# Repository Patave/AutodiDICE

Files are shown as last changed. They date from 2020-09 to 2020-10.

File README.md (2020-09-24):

# AutodiDICE
Electronic DICE
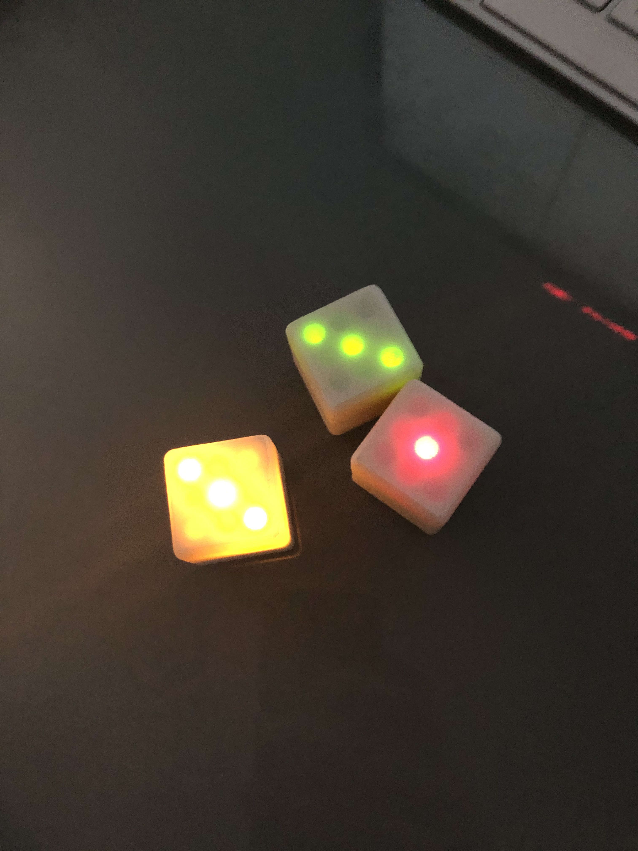
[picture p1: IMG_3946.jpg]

## Objectifs :

`Création Dé electronique sur base Attiny 85 et Attiny13A de A à Z`

Detection de vibration (switch mercure)

Mode Sleep et arret automatique après 7 secondes

Fonctionnel dans tous les sens (s'active sur un front montant du switch)

Ma Video: https://www.youtube.com/watch?v=F5hV5DrT228

3D STL Files: https://www.thingiverse.com/thing:4596834

Fichier GERBER pour production carte à souder

*Développement Electronique sous EasyEDA*

*Commande de cartes JLC-PCB*

### Principales réalisations : 

```
- Developpement Soft
  - Micro controlleur Attiny 85 + Evolution en Attiny13 pour encore diminuer le prix.
  - Fonction Sleep intégrée pour limiter la consommation
  - Animation du tirage dé amusante (rotation des leds) - pas possible pour la version Attiny13 (trop gros en octets)
  - V1.0: Verion Attiny85, v2.0: Version Attiny13

- Développement Electronique
  - réalisation sous EasyEDA
  - Génération image 3D (dans les fichiers joints)
  - Génération des fichiers GERBER pour lancement commande en Chine (JLC-PCB)

- Développpement boitier 3D
  - création du boitier sous Fusion 360
```

## Installation :

Attention à prévoir une petite découpe du support de pile pour laisser passer le microcontroleur

## Main components :

Attiny85: https://www.amazon.fr/Pièces-Attiny85-20PU-compatible-Arduino-A149/dp/B00OXVFD1I?pd_rd_w=Va80i&pf_rd_p=324a6047-fbee-4c30-8ff6-614657224ce8&pf_rd_r=Q6TFP13AJEMFBE4DBG9W&pd_rd_r=983145fe-9685-40ba-883b-0072b5635c12&pd_rd_wg=FvDhN&pd_rd_i=B00OXVFD1I&ref_=pd_bap_d_rp_1_11_t

Attiny13A (Evolution): https://fr.aliexpress.com/item/32751983292.html?spm=a2g0s.9042311.0.0.57206c37cBFwDP

Switch: https://fr.aliexpress.com/item/32605726248.html?spm=2114.13010708.0.0.3a996c37iu4wXC

Battery support: https://www.amazon.fr/GTIWUNG-Support-Adaptateurs-Batterie-Portables/dp/B0823WK4CN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

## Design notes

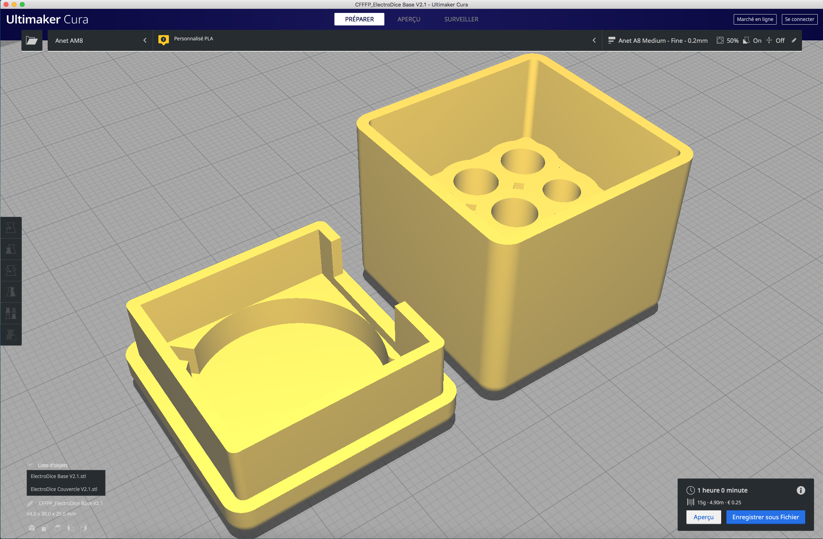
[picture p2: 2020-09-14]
Capture d’écran 2020-09-09 à 11.40.55.png

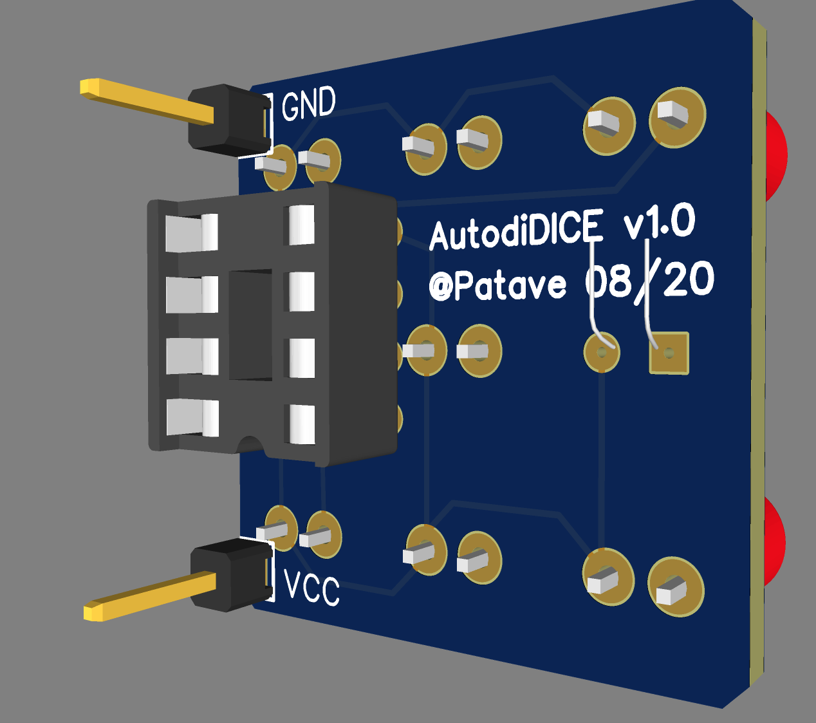
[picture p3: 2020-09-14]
Capture d’écran 2020-08-21 à 10.49.55.png

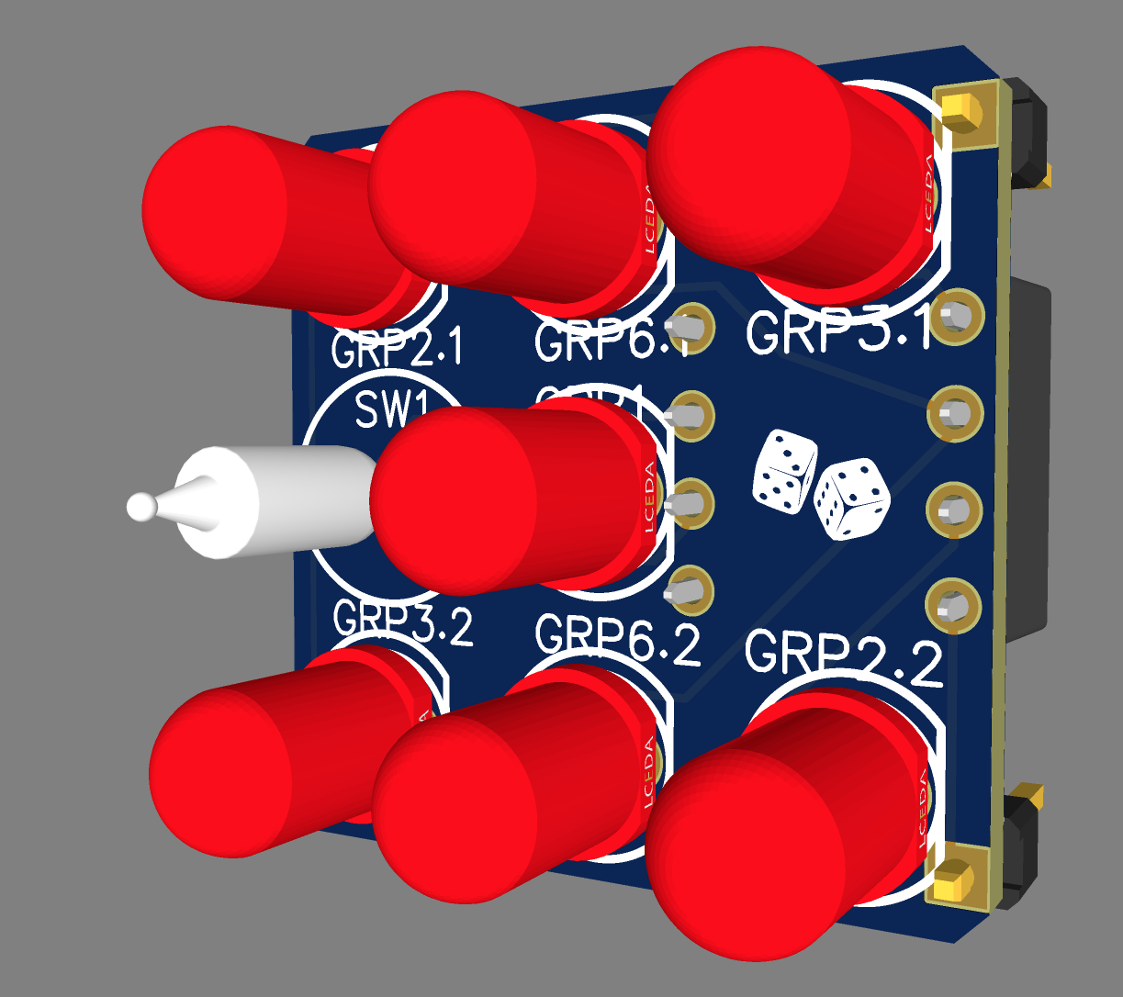
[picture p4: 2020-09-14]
Capture d’écran 2020-08-21 à 10.49.42.png

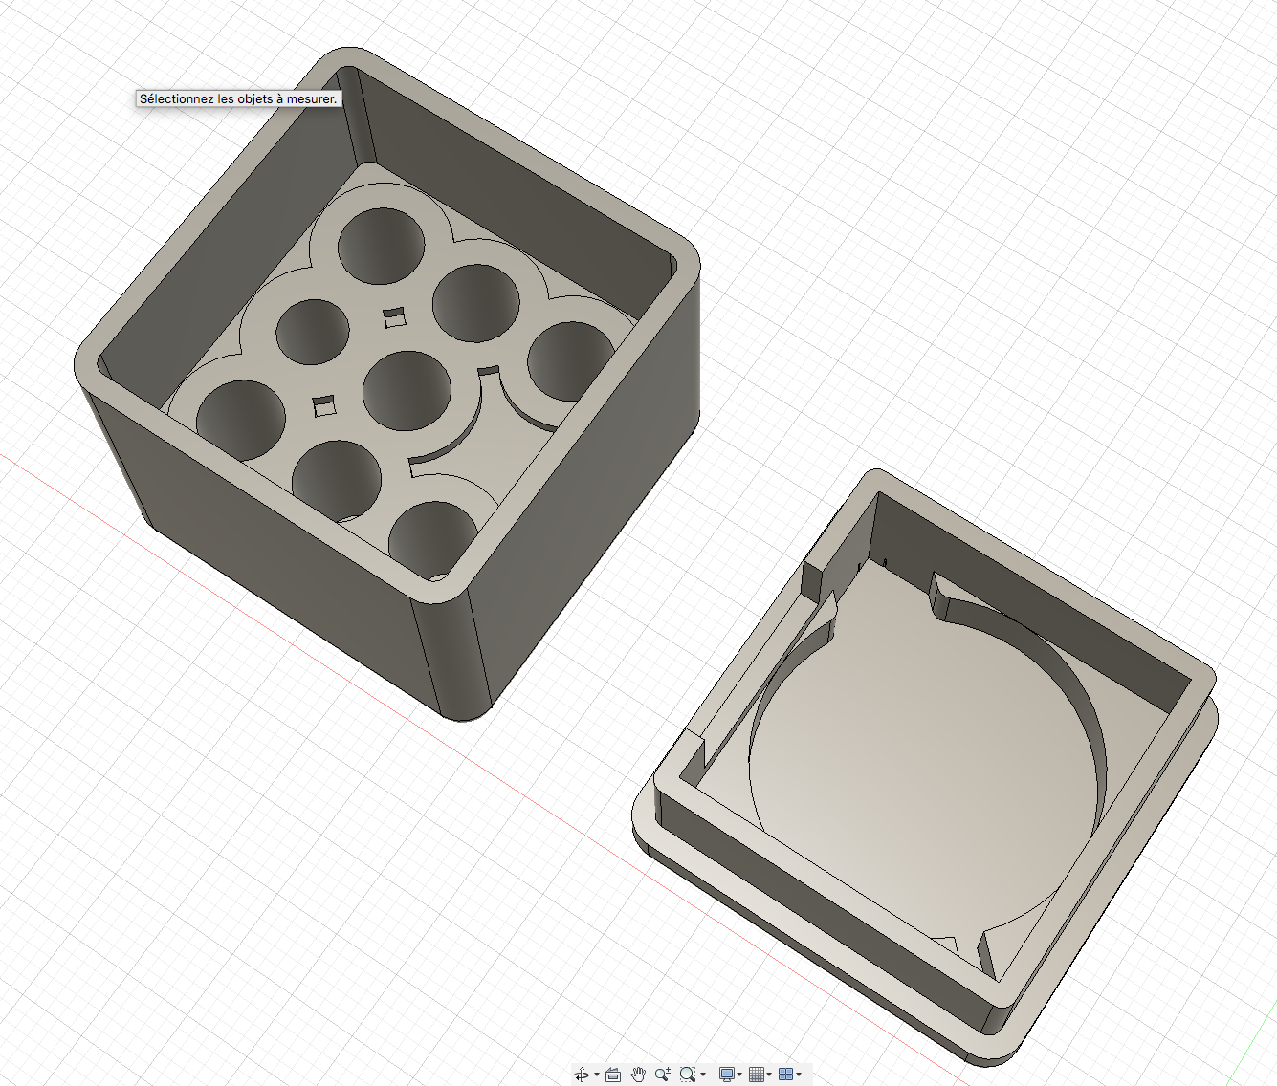
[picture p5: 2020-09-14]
Capture d’écran 2020-09-09 à 11.27.33.png

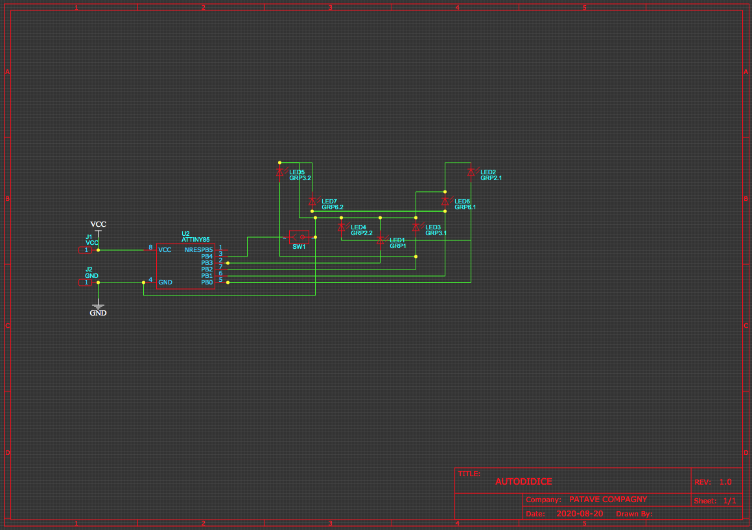
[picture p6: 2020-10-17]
AutodiDice Schema V1.0 2020-10-17.png

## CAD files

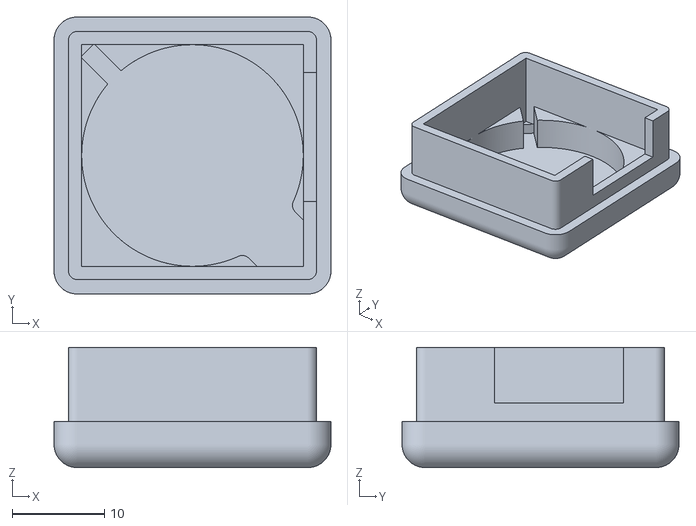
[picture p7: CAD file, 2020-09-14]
ElectroDice Base V2.1.stl
30.0 x 30.0 x 13.0

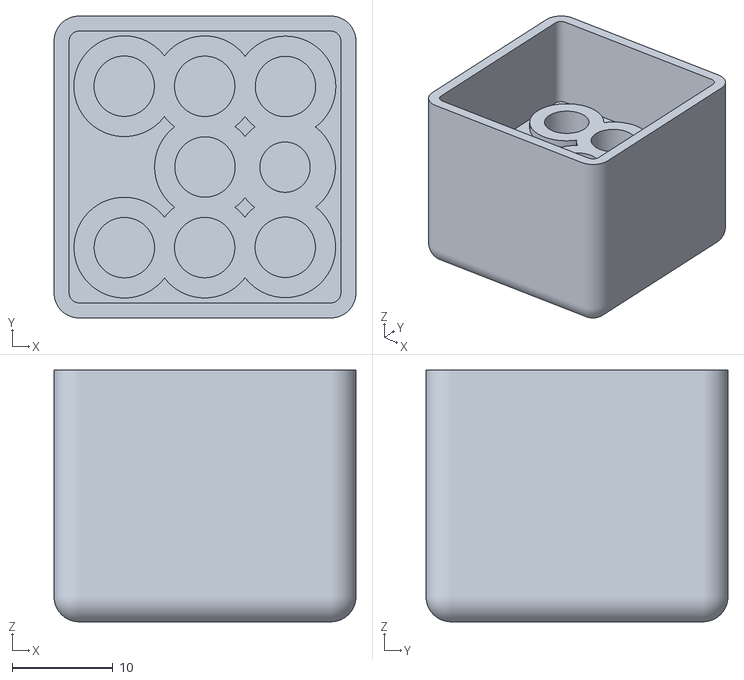
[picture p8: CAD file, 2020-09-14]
ElectroDice Couvercle V2.1.stl
30.0 x 30.0 x 25.0

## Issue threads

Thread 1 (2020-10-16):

schematics

claude1000, 2020-10-16:
Dear
could you post the schematics of the dice ?

nice job
thanks
Claude

Patave, 2020-10-17:
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

Hi Claude,
I will do.
But you have the gerber files if you want.
Patrick

Patave, 2020-10-17:
Claude, The schematic is now available

claude1000, 2020-10-20:
thanks a lot

Closed 2020-10-17.

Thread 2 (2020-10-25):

Led current-limiting resistor

claude1000, 2020-10-25:
Dear
Is there no need of resistors connected in serie with the led's  (  current-limiting resistor) ?
thanks a lot for the help
Claude

Patave, 2020-10-25:
No, with a battery 2032 it's ok

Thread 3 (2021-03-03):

Random not working?

rods, 2021-03-03:
I tried using ATTiny85 and ATTiny14 but the result is always 2, 4 or 6. There are no odd ones.
Compiled the v2 for both and v1 for ATTiny85. Results are the same

Patave, 2021-03-04:
Hi @rods , no reasons to randomize only for even numbers. Or you are very lucky.
I think that you have an hardware issue with the middle led.

rods, 2021-03-04:
Sorry @Patave ! shame on me!!! The center LED was down...fixed! This project is awesome...

Patave, 2021-03-04:
Great

Closed 2021-03-04.

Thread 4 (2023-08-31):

Attiny13

superjasiek, 2023-08-31:
Hi first have to say that it's realy  nice project. i made some dice with two types of chip - attiny85 and attiny13 i noticed that code with attiny13 consume much more power.
Dice with attiny85 last for weeks but dice with attiny13 works for maximum 6 days. Can you give me any hint how to solve the problem?
Thank you in advance for help.
Take care!

Patave, 2023-09-01:
@superjasiek You're right, I had the same behaviour.
The low consuption doesnt works. I have not investigate currently.

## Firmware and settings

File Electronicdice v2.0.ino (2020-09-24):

//------------------------------
// Dé électronique sur ATtiny13
// (C) 2020, Patrick Aversenq
//------------------------------
// Version "2.0", 24 september 2020

#include <avr/io.h>
#include <avr/sleep.h>
#include <avr/interrupt.h>
#include <util/delay.h>

// ----- DECLARATION DES VARIABLES ------

// Ports utilisée pour les groupes de LED:
//#define PortLeds PORTB
//#define BitUn PB3   // UN  (1 led centrale)
//#define BitDeux PB2 // DEUX (2 leds en coin)
//#define BitTrois PB0 // TROIS (2 leds en coin opposés)
//#define BitSix PB1 // SIX (2 leds milieu)

//#define PortButton PINB
//#define buttonPin PB4  //Capteur d'inclinaison


// Déclarations

int buttonState; //Etat du capteur d'inclinaison
int buttonPreviousState; //Etat capteur inclinaison précédent

unsigned long previousMillis = 0; //Time for activity

// Nombre de msseconde avant le sleep (Time Before Sleep)
#define Sleepdelay 7000


// Procédure pour afficher la valeur;
void Display (volatile byte *port, long valeur) {
   //Reset Port
   *port &= ~(_BV(PB0)|_BV(PB1)|_BV(PB2)|_BV(PB3));
   
   //Bit 1 (if value not even)
   if (valeur%2 != 0) *port |= _BV(PB3);
   
   //Bit 2 (if value > 1)
   if (valeur > 1) *port |= _BV(PB2);
  
   //Bit 3 (if value > 3)
   if (valeur > 3) *port |= _BV(PB0);
   
   //Bit 6 (if value > 5)
   if (valeur > 5) *port |= _BV(PB1);
   
   //short delay
   _delay_ms(200);
}


// Procédure de reveil (interruption)
ISR (PCINT0_vect) { // l'interruption termine le mode sleep
 sleep_disable();
 buttonPreviousState = LOW;
}


// Procédure de sommeil
void Sleep() {
  Display(&PORTB,0); //Eteind tout
  PCMSK|= _BV(PB4); // Pin Change sur PB3
  GIMSK|= _BV(PCIE); // Pin Change Interupt Inable

  set_sleep_mode(SLEEP_MODE_PWR_DOWN); // mieux: 3v à 2.5v en 10 sec.
  sleep_enable();
  sei(); // Lance l'interruption
  sleep_cpu(); // on passe en mode sleep.  
   // l'interruption le réveillera
}


// ----- DECLARATION ENTREES ET SORTIES ------
void setup ()
{
  //On indique que les LED sont des sorties  
  DDRB = (_BV(PB0)|_BV(PB1)|_BV(PB2)|_BV(PB3)); // sorties
  // On indique que le detecteur d'inclinaison est une entrée.
  PORTB= _BV(PB4); // entrée, avec Pull-up  pinMode (buttonPin, INPUT_PULLUP);
  //mode sleep after setup
  Sleep(); 
}

// ----- BOUCLE ------
void loop()
{ 
  unsigned long currentMillis = millis();
  // Variable pour le random du résultat final
  long ran;

  buttonState = digitalRead(PB4);

  if ((buttonState!=buttonPreviousState) && (buttonState == HIGH)) { // Si on bouge le dé (detection front)
   //SMALL ANIMATION FOR SUSPENS !!!  
    for (int i = 6; i >= 0 ; i--) {
      Display(&PORTB,i);
    }
    _delay_ms(300);
   
    // RANDOM DU RESULTAT FINAL
    ran = random(1, 7); //Random value between >=1 and <7 (1 to 6)
    Display (&PORTB, ran); //Affiche le tirage
    
    
    //réinitialise le timer d'activité; 
    currentMillis = millis();
    previousMillis = currentMillis;
    buttonPreviousState = buttonState;
  }

  //SLEEP MODE DETECTION
  if (currentMillis - previousMillis >= Sleepdelay) { //Time of Activity closed
       // save the last time you measure
      previousMillis = currentMillis;
      Sleep(); // Endormissement
   }

}
